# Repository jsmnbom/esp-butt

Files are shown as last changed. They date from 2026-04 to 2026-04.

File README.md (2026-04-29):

# esp-butt

Bluetooth intimate hardware (sex toys, etc) controller powered by [buttplug.io](https://buttplug.io/).

## Status

This project is still in fairly early development, it has some quirks and rough edges but is generally functional. Feel free to contact me if you are interested in building your own or contributing to the project.

## Documentation

<div align="center">
  <table>
    <tr>
      <td><h3 align="center"><a href="https://jsmnbom.github.io/esp-butt/">🏠<br/>Home</a></h3></td>
      <td><h3 align="center"><a href="https://jsmnbom.github.io/esp-butt/hardware">🛠️<br/>Hardware</a></h3></td>
      <td><h3 align="center"><a href="https://jsmnbom.github.io/esp-butt/hardware">📋<br/>BOM</a></h3></td>
      <td><h3 align="center"><a href="https://jsmnbom.github.io/esp-butt/hardware">📐<br/>Schematic</a></h3></td>
      <td><h3 align="center"><a href="https://jsmnbom.github.io/esp-butt/hardware">🟩<br/>PCB</a></h3></td>
      <td><h3 align="center"><a href="https://jsmnbom.github.io/esp-butt/hardware">🧊<br/>3D Models</a></h3></td>
      <td><h3 align="center"><a href="https://jsmnbom.github.io/esp-butt/firmware">⚙️<br/>Firmware</a></h3></td>
    </tr>
  </table>
</div>

## Contributing

I welcome contributions with open arms. If you have ideas, suggestions for improvements, or want to help out with development, please don't hesitate to reach out or submit a pull request.

## License

This project uses multiple licenses depending on the component:

| Component | License |
|---|---|
| `src/` — firmware source code | [MIT](https://opensource.org/licenses/MIT) |
| `docs/` — documentation | [MIT](https://opensource.org/licenses/MIT) |
| `cad/` — CAD files | [MIT](https://opensource.org/licenses/MIT) |
| `img/` — images | [CC BY-SA 4.0](https://creativecommons.org/licenses/by-sa/4.0/) |
| `pcb/` — PCB design | [CC BY-SA 4.0](https://creativecommons.org/licenses/by-sa/4.0/) |
| `pcb/kicad-config/10.0/colors/witchhazel.json` | [Apache-2.0](https://www.apache.org/licenses/LICENSE-2.0) — © [Thea Flowers](https://github.com/theacodes/witchhazel) |
| `pcb/esp-butt/3D/` — 3D models | Mixed — see [ATTRIBUTION.md](pcb/esp-butt/3D/ATTRIBUTION.md) |

## Thanks

Thanks to @qdot and the rest of the Buttplug.io contributors doing all the hard work of reverse engineering and protocol design, and also for being generally awesome.

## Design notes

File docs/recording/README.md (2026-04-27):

# Recording artifacts

This directory holds the raw session recording used to build the hero animation.

## How to populate

1. Run the firmware with recording enabled:
   ```bash
   ESP_BUTT_RECORD_SESSION=1 cargo run
   ```
2. Copy the recording files here:
   ```bash
   cp /tmp/esp-butt-session.ndjson docs/recording/session.ndjson
   cp /tmp/esp-butt-session.gif docs/recording/session.gif
   ```

   `session.ndjson` and `session.gif` are imported directly by Vite as part of the
   docs bundle — no separate build step is required.

## Files

- `session.ndjson` — raw event log (NDJSON, one event per line); frame events reference GIF frame indices
- `session.gif` — OLED frame snapshots stored as an animated GIF (used as a frame container)

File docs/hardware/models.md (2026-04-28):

# 3D Models

<script setup>
import {
  caseTopGlb, caseBottomGlb, encoderKnobGlb, sliderKnobGlb, powerSwitchCapGlb,
  caseTopStepUrl, caseBottomStepUrl, encoderKnobStepUrl,
  sliderKnobBodyStepUrl, sliderKnobInsertStepUrl, powerSwitchCapStepUrl,
} from '../.vitepress/theme/composables/models';
</script>

All parts are designed in [build123d](https://build123d.readthedocs.io/en/latest/) with custom helpers. Source notebooks are in the [`cad/`](https://github.com/jsmnbom/esp-butt/tree/main/cad) directory.

## Printing

The models are designed around my **Voron V2.4** printer. Other printers should work, but tolerances on snap-fits and clearance holes are tuned to my machine, so some adjustment may be needed.

**Material:** ABS is recommended for durability and dimensional stability. I use filament from [TM3D Filament](https://tm3dfilament.com/) (no affiliation).

**Slicer:** All parts were sliced with **OrcaSlicer**.

**General settings:** 0.15 mm layer height · 3 wall loops · 15–25% gyroid infill.

**Orientation:** All parts should be printed in the orientation in the step files.

## Case

2 wall loops is sufficient. Set outer wall width to **0.4 mm** — required for the slicer to handle the antenna cutout geometry correctly. Seam position and seam scarf/gap settings may need to be tuned to hide the seam on visible faces.

### Case Top

<StepDownload :files="{ name: 'case_top', url: caseTopStepUrl }" />

<ClientOnly>
  <CadViewer :url="caseTopGlb"/>
</ClientOnly>

### Case Bottom

<StepDownload :files="{ name: 'case_bottom', url: caseBottomStepUrl }" />

<ClientOnly>
  <CadViewer :url="caseBottomGlb"/>
</ClientOnly>

## Encoder knob

1 wall loop. Use a **concentric** top surface pattern to give the concave top a smooth feel.

<StepDownload :files="{ name: 'encoder_knob', url: encoderKnobStepUrl }" />

<ClientOnly>
  <CadViewer :url="encoderKnobGlb"/>
</ClientOnly>

## Slider knob

**Body:** 1 wall loop. Use an **aligned rectilinear** top surface pattern with infill direction set to **0°** — this makes the knob divots noticeably smoother.

**Inserts:** Print flat. Use **0.12 mm layer height** and a very slow print speed — these are small precision parts and quality matters here.

<StepDownload :files="[{ name: 'slider_knob_body', url: sliderKnobBodyStepUrl }, { name: 'slider_knob_insert', url: sliderKnobInsertStepUrl }]" />

<ClientOnly>
  <CadViewer :url="sliderKnobGlb"/>
</ClientOnly>

## Power switch cap

General settings apply.

<StepDownload :files="{ name: 'power_switch_cap', url: powerSwitchCapStepUrl }" />

<ClientOnly>
  <CadViewer :url="powerSwitchCapGlb"/>
</ClientOnly>

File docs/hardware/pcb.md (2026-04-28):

# PCB

PCB design files are available in the [`pcb/`](https://github.com/jsmnbom/esp-butt/tree/main/pcb) directory. The PCB was designed using KiCad, and the source files are included.

<PCBViewer />

## Manufacturing

The PCBs for this project were manufactured at [Aisler](https://aisler.net). They are a European fab, I went with them for their strong focus on hobbyist and maker customers, good reviews for quality and support, and convenient shipping options.

Aisler also offers two stackable discounts worth knowing about:

- **LOGO Hack** — a checkbox during checkout that grants a 25% discount in exchange for the Aisler logo being placed on the board (the PCB already has a designated area for this).
- **Part Professional program** — when boards include parts from specific vendors you get a discount on the PCB cost. For this PCB the rotary encoder and 1x4 pin socket header can be sourced from Würth Elektronik which take advantage of this program.

With these combined, 3 PCBs including fast shipping and the KiCad sponsor contribution comes to around **€35** at the time of writing.

Alternative fabs such as JLCPCB or PCBWay may offer lower prices, but I have not tested them with this specific board. They may require adjustments to export settings and may have longer turnaround times depending on shipping options. However the board overall is quite simple and should be compatible with a wide range of manufacturers.

## 3D Preview

<script setup>
import { pcbGlb } from '../.vitepress/theme/composables/models';
</script>

<ClientOnly>
  <CadViewer :url="pcbGlb"/>
</ClientOnly>

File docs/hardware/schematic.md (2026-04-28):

---
aside: false
---

# Schematic

<SchematicViewer />

## Design Notes

### Power switch

S2 is a **DPDT (double pole, double throw)** slide switch used to cut power in two places simultaneously. One pole interrupts the VCC rail to all peripherals — the display, encoder, and sliders — so they draw no current when off. The other pole holds the ESP32-S3's **EN pin low**, which suspends the chip entirely rather than leaving it in an idle loop.

This is a pragmatic design choice that avoids idle current draw without requiring deep sleep firmware support. The trade-off is that it's a somewhat unconventional use of the EN pin. A cleaner future revision would use proper deep sleep mode combined with a P-channel MOSFET or a dedicated load switch IC on the battery rail, which would allow the firmware to participate in the power-down sequence and wake from user input.

### Battery

The controller is powered by a **3.7 V LiPo cell** (600 mAh recommended, see links in BOM) connected via a JST-PH connector (J2). There is no on-board charging circuit — the battery must be charged externally, for example with a standalone TP4056 module. This keeps the board simple and small, but means you'll need to disconnect the battery and charge it separately.

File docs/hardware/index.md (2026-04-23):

# Hardware Overview

esp-butt is a handheld Bluetooth controller built around the ESP32-S3. It connects to BLE intimate devices running the [Buttplug protocol](https://buttplug.io/) and lets you control them through a small physical interface: an OLED display, a rotary encoder, and three analog sliders.

## Components

| Component | Details |
|---|---|
| **MCU** | ESP32-S3 (Xtensa dual-core, 240 MHz, Wi-Fi + BLE) |
| **Display** | 128×64 OLED, I²C (SH1106) |
| **Encoder** | Rotary encoder with push button — menu navigation and selection |
| **Sliders** × 2 | 10 kΩ linear potentiometers — analog control of device features (intensity, oscillation, etc.) |
| **Power** | LiPo battery |

## Sections

- **[Bill of Materials](/hardware/bom)** — Full parts list with quantities and purchase links.
- **[Schematic](/hardware/schematic)** — Circuit diagram for the controller board.
- **[PCB](/hardware/pcb)** — KiCad PCB layout and 3D preview.
- **[3D Models](/hardware/models)** — Printable case, knobs, and power switch cap.

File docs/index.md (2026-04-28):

---
layout: home

hero:
  name: "esp-butt"
  text: "A physical controller for intimate devices"
  tagline: "No phone. No app. Just knobs, sliders, and hundreds of compatible toys."
  actions:
    - theme: brand
      text: Hardware
      link: /hardware/
    - theme: alt
      text: Firmware
      link: /firmware/
    - theme: alt
      text: GitHub
      link: https://github.com/jsmnbom/esp-butt

features:
  - icon: i-noto-v1:no-mobile-phones
    title: No phone required
    details: A standalone physical controller — power it on, pick a device from the OLED menu, and you're in control. No app, no pairing ceremony.
  - icon: i-logos:bluetooth
    title: Works with hundreds of toys
    details: Built on Buttplug.io, the open intimacy device protocol. If your toy speaks BLE and Buttplug knows it, this controller can drive it.
  - icon: i-whh:controlpanel
    title: Hands-on controls
    details: Two analog sliders and a rotary encoder with push-click give precise, tactile control over intensity — no touchscreen fumbling.
  - icon: i-logos:opensource
    title: Fully open source
    details: KiCad schematics, 3D-printable case, and Rust firmware — everything needed to build, modify, or extend your own unit.
    link: /hardware/
    linkText: Build one
---

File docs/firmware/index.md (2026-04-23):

# Firmware

## Flashing Pre-built Firmware

Pre-built firmware binaries are published with each [GitHub release](https://github.com/jsmnbom/esp-butt/releases). Download the latest `.bin` file from there.

### Flashing with espflash

Install [espflash](https://github.com/esp-rs/espflash):

```sh
cargo install espflash --locked
```

Then flash the downloaded binary:

```sh
espflash flash --chip esp32s3 esp-butt.bin
```

## Building from Source

### Prerequisites

Install the Espressif toolchain:

```sh
cargo install espup --locked
espup -t esp32s3 -s --toolchain-version 1.93.0.0
```

The toolchain uses the `esp` channel (Espressif's Xtensa fork). Target triple: `xtensa-esp32s3-espidf`.

### Build and Flash

Switch the build target to `xtensa-esp32s3-espidf` in `.cargo/config.toml` (and `.vscode/settings.json` for rust-analyzer):

```sh
cargo build          # debug build
cargo run            # build, flash, and open serial monitor
```

`cargo run` flashes via `espflash flash --monitor` as configured in `.cargo/config.toml`.

### Desktop Mock (no device needed)

Switch the target to `x86_64-unknown-linux-gnu`:

```sh
cargo run
```

Requires the [kitty](https://sw.kovidgoyal.net/kitty/) terminal emulator. The display output renders in a separate kitty window. Use mouse to interact with sliders and keyboard arrows + Enter to simulate button presses.

---

## Architecture

- `src/app/` — platform-independent state machine and UI screens
- `src/ble/` — NimBLE BLE scanning and GATT client (ESP only)
- `src/buttplug/` — Buttplug server/client, device config, deferred connection approval
- `src/hw/` — display (I2C OLED), encoder, sliders, ticker; split into `hw/esp/` and `hw/mock/`
- `src/utils/` — FreeRTOS task spawning, PSRAM heap, logging

CPU affinity: BLE on Core 0, app logic on Core 1.

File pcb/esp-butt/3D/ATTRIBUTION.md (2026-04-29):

# 3D Model Attribution

| File(s) | Source | License / Terms |
|---|---|---|
| `AZ-Delivery - OLED13 IIC -0.6.step`<br>`AZ-Delivery - OLED13 IIC - split.step` | Modified from [GrabCAD](https://grabcad.com/library/1-3-oled-display-128x64-1) | [GrabCAD Terms of Use](https://grabcad.com/terms) |
| `C_Disc_D5.0mm_W2.5mm_P2.50mm.step`<br>`JST_PH_B2B-PH-K_1x02_P2.00mm_Vertical.step`<br>`PinSocket_1x04_P2.54mm_Vertical.step`<br>`R_Axial_DIN0207_L6.3mm_D2.5mm_P10.16mm_Horizontal.step` | [KiCad official library](https://gitlab.com/kicad/libraries/kicad-packages3D) | [CC BY-SA 4.0](https://creativecommons.org/licenses/by-sa/4.0/) |
| `PBH2UEESNPNAGX.step` | [SnapEDA](https://www.snapeda.com/parts/PBH2UEESNPNAGX/E-Switch/view-part/) | [SnapEDA Terms of Use](https://www.snapeda.com/about/terms/) |
| `PEC12R-4225F-S0024.step` | [SnapEDA](https://www.snapeda.com/parts/PEC12R-4225F-S0024/Bourns/view-part/) | [SnapEDA Terms of Use](https://www.snapeda.com/about/terms/) |
| `PTA4543-2015DPB103-fixed.step`<br>`PTA4543-2015DPB103-fixed2.step` | Modified from [ComponentSearchEngine](https://componentsearchengine.com/part-view/PTA4543-2015DPB103/Bourns) | [Samacsys Terms of Use](https://componentsearchengine.com/terms-and-conditions) |
| `XIAO-ESP32S3 v2Seeed Studio XIAO-ESP32-S3.step` | [Seeed Studio](https://files.seeedstudio.com/wiki/SeeedStudio-XIAO-ESP32S3/res/seeed-studio-xiao-esp32s3-3d_model.zip) | [Seeed Studio Terms](https://www.seeedstudio.com/terms-of-use.html) |

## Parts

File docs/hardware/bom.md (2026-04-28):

---
aside: false
---

# Bill of Materials

> **Note:** The purchase links listed here may include referral or promotional codes. The specific parts linked have not all been individually tested, but are strongly believed to be functionally compatible with the design. If you source equivalent parts elsewhere, check the datasheet to confirm pinout and electrical ratings match.

<ClientOnly>
  <BomTable />
</ClientOnly>

> **Note:** Add `Source_EU` and `Source_US` URL fields to components in KiCad to populate the buy links above.

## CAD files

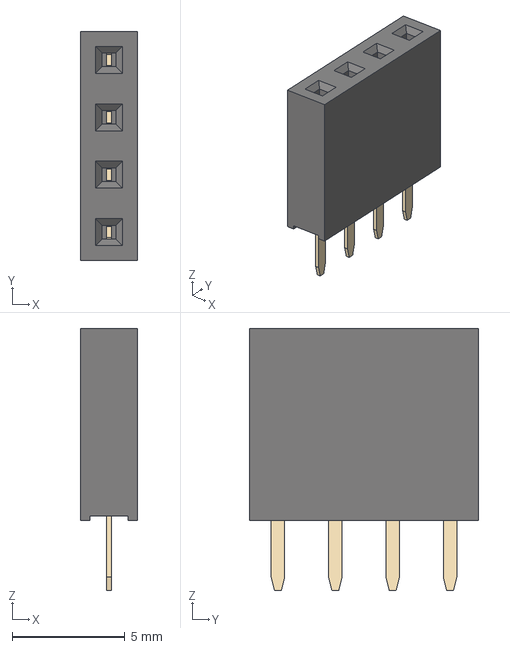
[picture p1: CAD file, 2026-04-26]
pcb/esp-butt/3D/PinSocket_1x04_P2.54mm_Vertical.step
2.54 x 10.2 x 11.6 mm

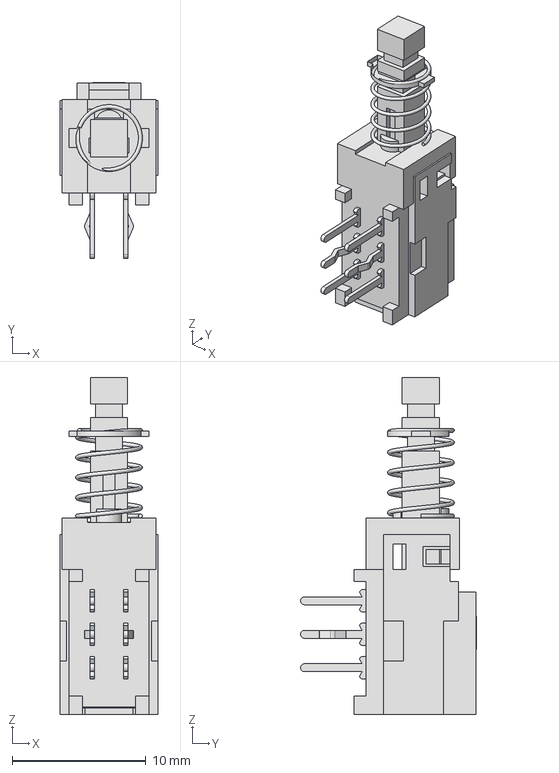
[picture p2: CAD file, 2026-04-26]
pcb/esp-butt/3D/PBH2UEESNPNAGX.step
7.30 x 13.2 x 25.2 mm

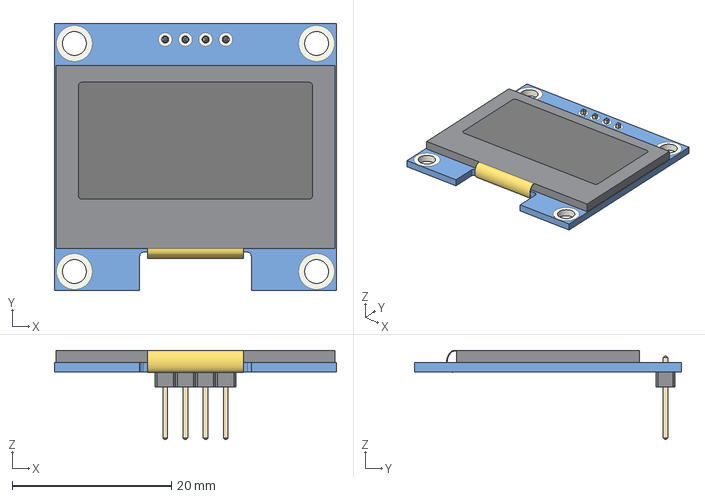
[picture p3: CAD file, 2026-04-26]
pcb/esp-butt/3D/AZ-Delivery - OLED13 IIC - split.step
35.4 x 33.5 x 11.2 mm
Base
Screen

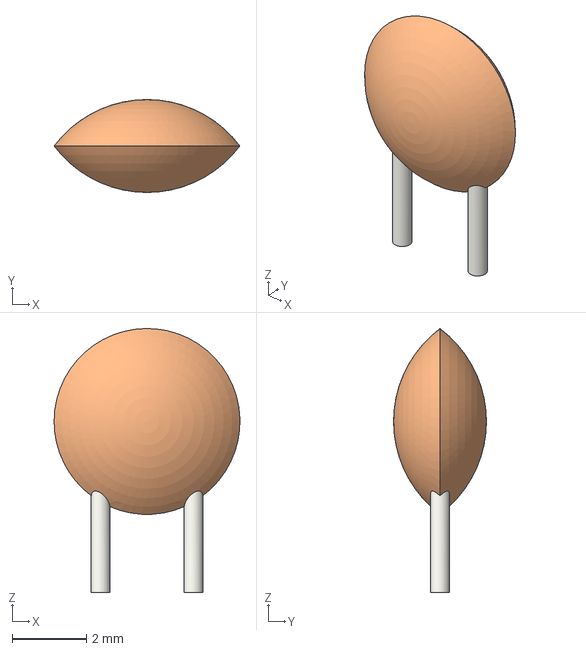
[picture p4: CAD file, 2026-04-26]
pcb/esp-butt/3D/C_Disc_D5.0mm_W2.5mm_P2.50mm.step
5.00 x 2.50 x 7.10 mm

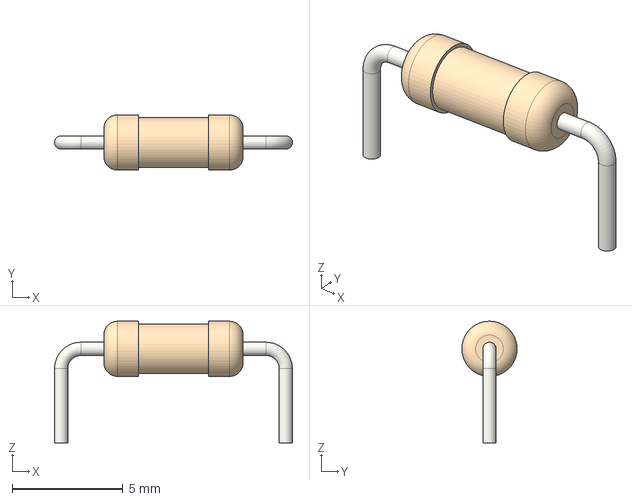
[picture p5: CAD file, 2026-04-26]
pcb/esp-butt/3D/R_Axial_DIN0207_L6.3mm_D2.5mm_P10.16mm_Horizontal.step
10.8 x 2.50 x 5.50 mm

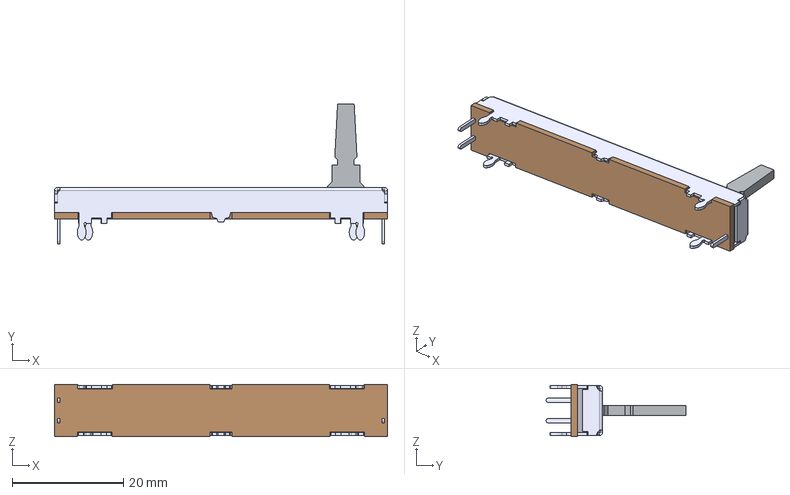
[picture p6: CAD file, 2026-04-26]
pcb/esp-butt/3D/PTA4543-2015DPB103-fixed2.step
60.0 x 25.2 x 9.40 mm
Shield
PCB
Pin1
Pin2
Pin3
Inner
Lever

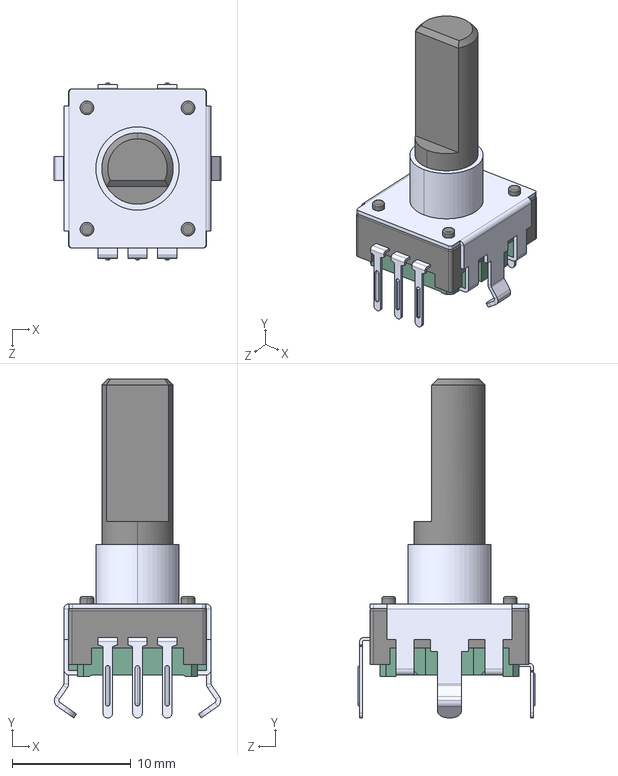
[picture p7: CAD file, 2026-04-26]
pcb/esp-butt/3D/PEC12R-4225F-S0024.step
14.0 x 28.5 x 14.9 mm

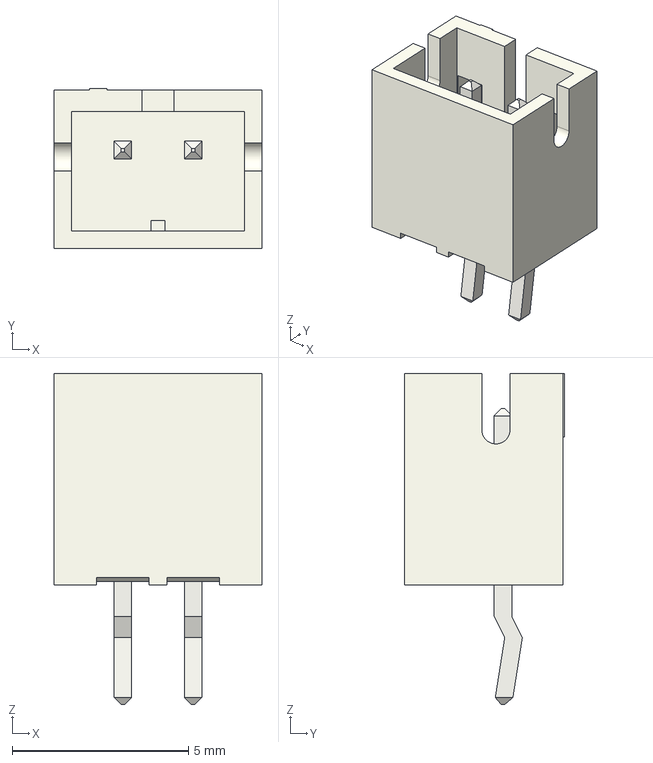
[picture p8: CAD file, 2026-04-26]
pcb/esp-butt/3D/JST_PH_B2B-PH-K_1x02_P2.00mm_Vertical.step
5.90 x 4.55 x 9.40 mm

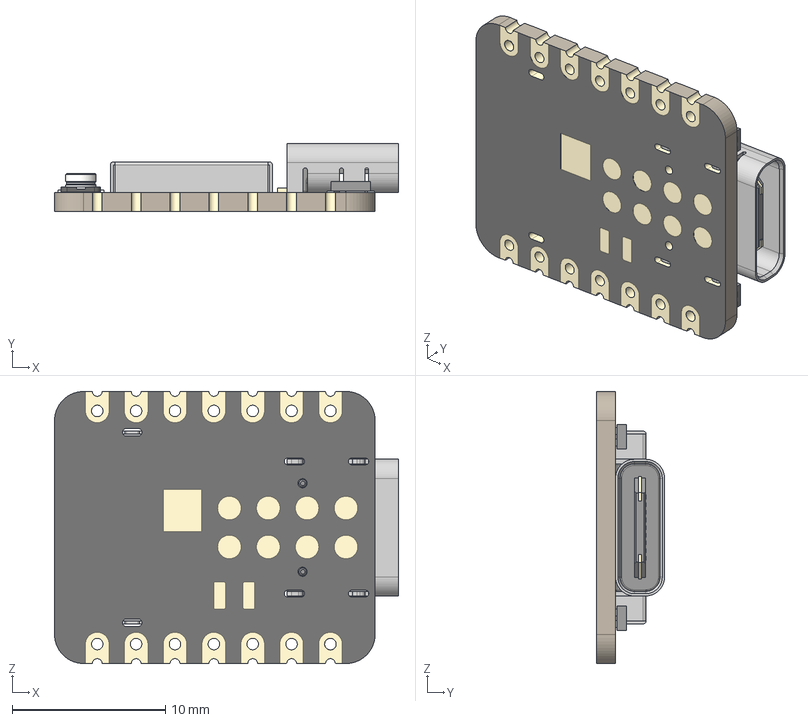
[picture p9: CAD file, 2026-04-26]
pcb/esp-butt/3D/XIAO-ESP32S3 v2Seeed Studio XIAO-ESP32-S3.step
22.5 x 4.46 x 17.8 mm
BOSS-EXTRUDE14_8_
BOSS-EXTRUDE7_4_
BOSS-EXTRUDE7_3_
BOSS-EXTRUDE14_4_
BOSS-EXTRUDE14_2_
BOSS-EXTRUDE14_11_
BOSS-EXTRUDE7_7_
BOSS-EXTRUDE14_9_
BOSS-EXTRUDE14_3_
BOSS-EXTRUDE14_7_
MIRROR2
BOSS-EXTRUDE14_5_
BOSS-EXTRUDE14_12_
BOSS-EXTRUDE7_8_
BOSS-EXTRUDE7_1_
BOSS-EXTRUDE14_10_
BOSS-EXTRUDE7_9_
BOSS-EXTRUDE14_6_
BOSS-EXTRUDE14_1_
BOSS-EXTRUDE7_6_
BOSS-EXTRUDE7_2_
CUT-EXTRUDE5
BOSS-EXTRUDE7_5_
Shield
Pins x 2
Pins001 x 2
Pins002 x 2
Pins003 x 2
U.FL-R-SMT-1_10_ v1

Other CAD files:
pcb/esp-butt/3D/AZ-Delivery - OLED13 IIC -0.6.step
pcb/esp-butt/3D/PTA4543-2015DPB103-fixed.step

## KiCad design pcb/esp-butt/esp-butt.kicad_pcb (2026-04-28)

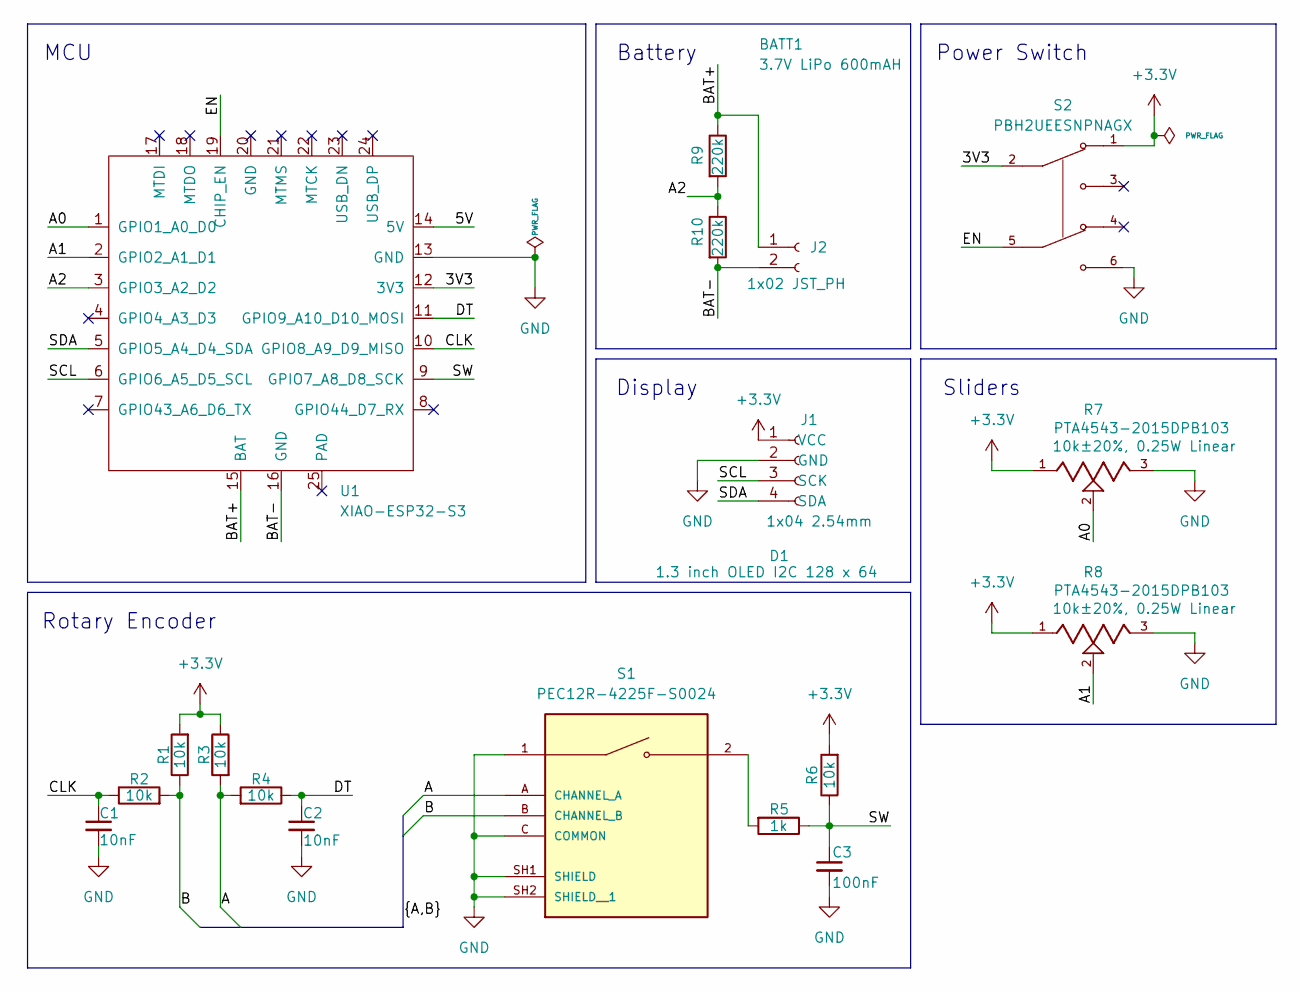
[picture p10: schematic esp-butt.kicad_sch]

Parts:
BATT1: 3.7V LiPo 600mAH
C1, C2: 10nF; C_Disc_D5.0mm_W2.5mm_P2.50mm
C3: 100nF; C_Disc_D5.0mm_W2.5mm_P2.50mm
D1: 1.3 inch OLED I2C 128 x 64
J1: 1x04 2.54mm; OLED_128x64_1.3in_I2C_Socket_Vertical
J2: 1x02 JST_PH; JST_PH_B2B-PH-K_1x02_P2.00mm_Vertical
R1, R2, R3, R4, R6: 10k; R_Axial_DIN0207_L6.3mm_D2.5mm_P10.16mm_Horizontal
R5: 1k; R_Axial_DIN0207_L6.3mm_D2.5mm_P10.16mm_Horizontal
R7, R8: PTA4543-2015DPB103; TRIM_PTA4543-2015DPB103; PARTREV 04/21
R9, R10: 220k; R_Axial_DIN0207_L6.3mm_D2.5mm_P10.16mm_Horizontal
S1: PEC12R-4225F-S0024; XDCR_PEC12R-4225F-S0024; PARTREV 07/21
S2: PBH2UEESNPNAGX; SW_PBH2UEESNPNAGX; PARTREV E
U1: XIAO-ESP32-S3; XIAO-ESP32-S3-DIP+

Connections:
+3.3V: J1.1 (VCC), R1.2, R3.1, R6.2, R7.1, R8.1, S2.1
/3V3: S2.2, U1.12 (3V3)
/5V: U1.14 (5V)
/A: R3.2, R4.2, S1.A (CHANNEL_A)
/A0: R7.2, U1.1 (GPIO1_A0_D0)
/A1: R8.2, U1.2 (GPIO2_A1_D1)
/A2: R9.2, R10.1, U1.3 (GPIO3_A2_D2)
/B: R1.1, R2.2, S1.B (CHANNEL_B)
/BAT+: J2.1, R9.1, U1.15 (BAT)
/BAT-: J2.2, R10.2, U1.16 (GND)
/CLK: C1.1, R2.1, U1.10 (GPIO8_A9_D9_MISO)
/DT: C2.1, R4.1, U1.11 (GPIO9_A10_D10_MOSI)
/EN: S2.5, U1.19 (CHIP_EN)
/SCL: J1.3 (SCK), U1.6 (GPIO6_A5_D5_SCL)
/SDA: J1.4 (SDA), U1.5 (GPIO5_A4_D4_SDA)
/SW: C3.1, R5.1, R6.1, U1.9 (GPIO7_A8_D8_SCK)
GND: C1.2, C2.2, C3.2, J1.2 (GND), R7.3, R8.3, S1.1, S1.C (COMMON), S1.SH1 (SHIELD), S1.SH2 (SHIELD__1), S2.6, U1.13 (GND)
unnamed: R5.2, S1.2

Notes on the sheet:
Display
Power Switch
Rotary Encoder
Sliders
MCU
Battery

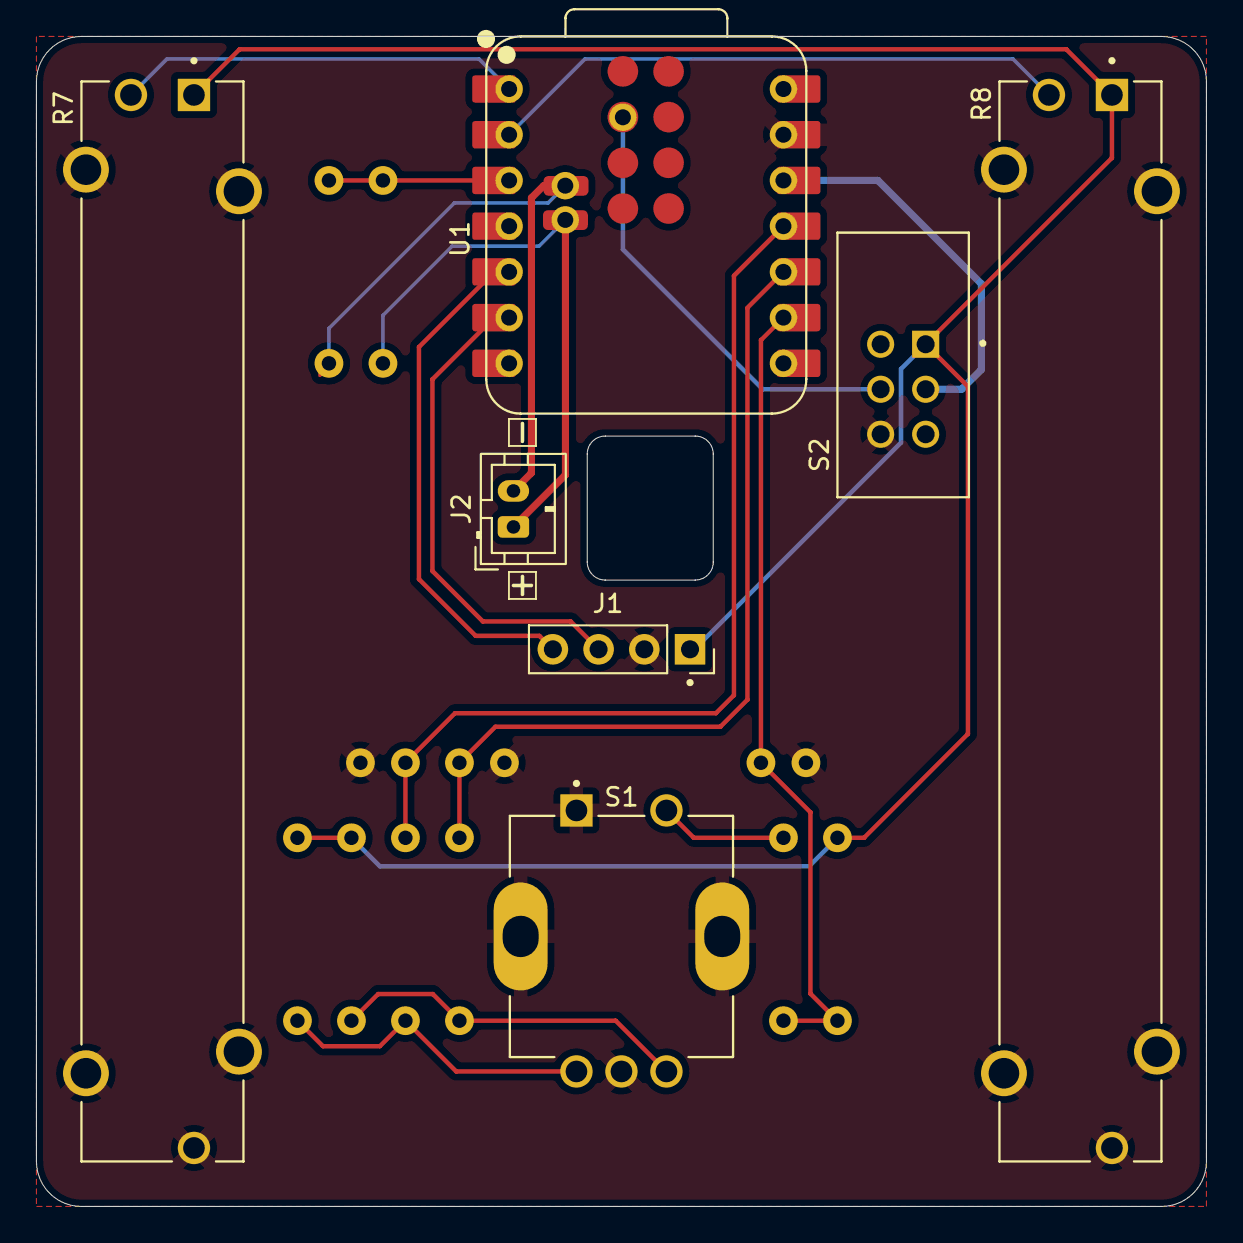
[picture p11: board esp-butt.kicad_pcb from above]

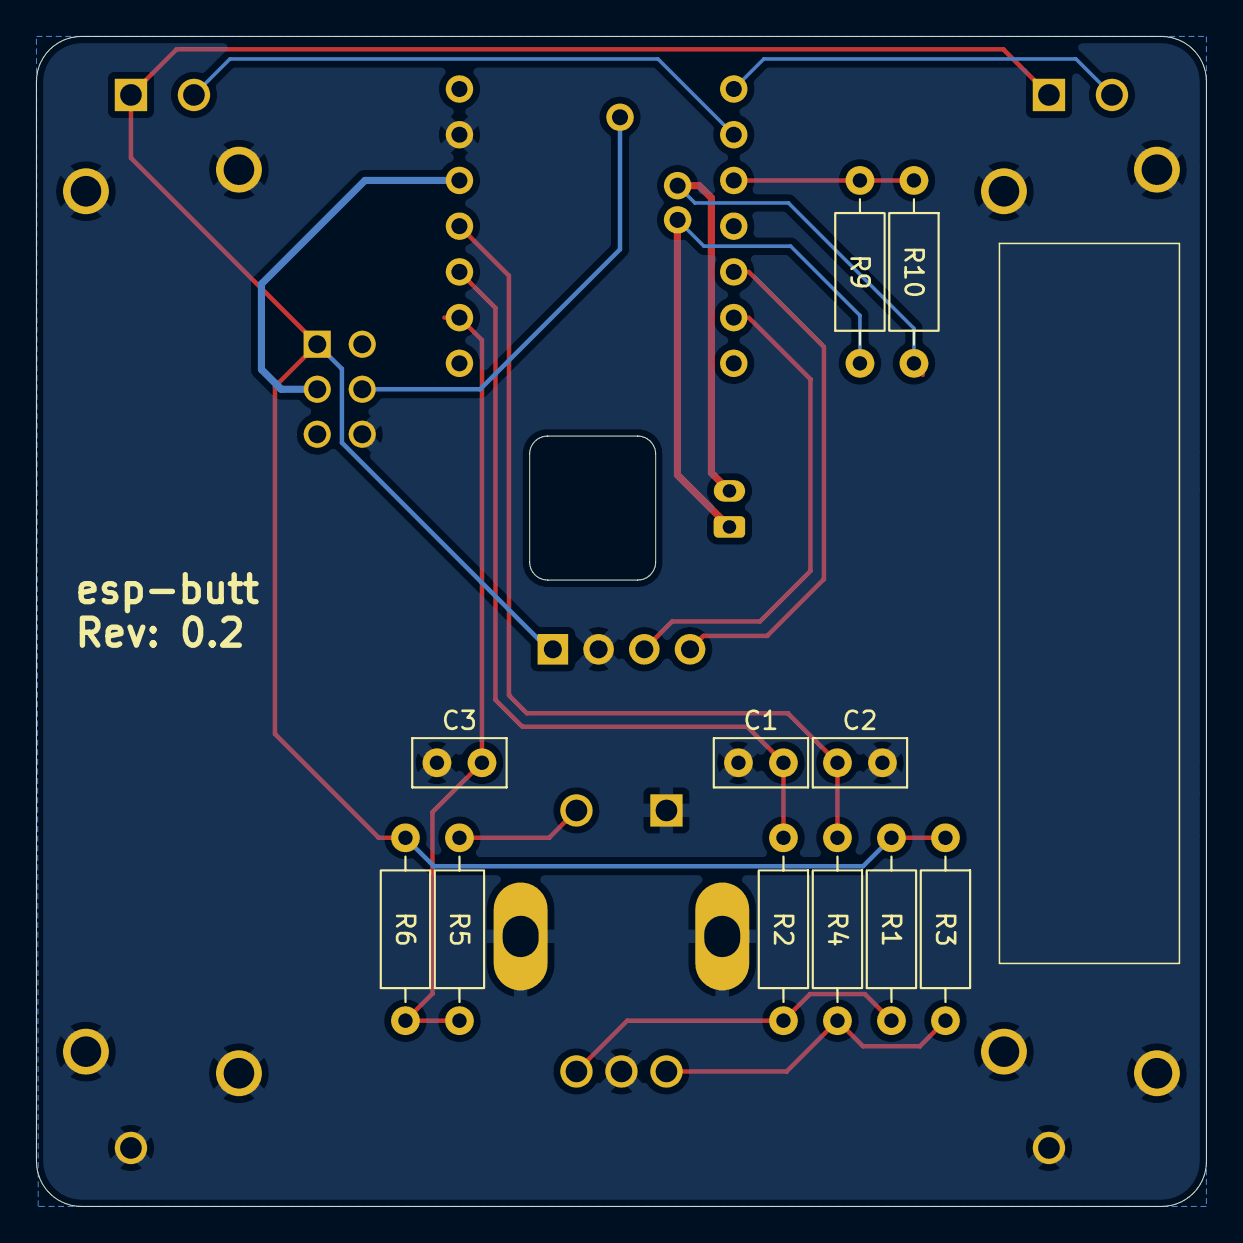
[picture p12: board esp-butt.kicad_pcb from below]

Board: 2 copper layers, 65.0 x 65.0 mm, 18 parts (11 on the bottom side), 17 nets.

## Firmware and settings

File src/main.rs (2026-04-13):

mod app;
mod buttplug;
mod hw;
mod img;
mod utils;

#[cfg(target_os = "espidf")]
mod ble;

#[cfg(target_os = "espidf")]
fn main() -> anyhow::Result<()> {
  use futures_concurrency::prelude::*;

  esp_idf_svc::sys::link_patches();

  tracing_log::LogTracer::init().unwrap();

  utils::log::Subscriber::new(tracing::Level::DEBUG)
    .with_filter("esp_idf_svc::timer", tracing::Level::WARN)
    .with_filter("buttplug", tracing::Level::DEBUG)
    .install();

  hw::init()?;
  ble::init();
  buttplug::init();

  // utils::report::start_reporting(core::time::Duration::from_secs(5));

  log::info!("Hello, world!");

  let peripherals = esp_idf_svc::hal::peripherals::Peripherals::take().unwrap();

  let display = hw::Display::new(
    peripherals.i2c0,
    peripherals.pins.gpio5,
    peripherals.pins.gpio6,
  )?;

  let adc = hw::AdcInputs::new(
    peripherals.adc1,
    (peripherals.pins.gpio1, peripherals.pins.gpio2),
    peripherals.pins.gpio3,
  )?;

  let encoder = hw::Encoder::new(
    peripherals.pins.gpio9,
    peripherals.pins.gpio8,
    peripherals.pins.gpio7,
  )?;

  let ticker = hw::Ticker::new()?;

  let input_event_stream = Box::pin((adc.stream(), encoder.stream(), ticker.stream()).merge());

  let app = app::App::new(display, adc);

  esp_idf_svc::hal::task::block_on(async move { app.main(input_event_stream).await })
}

#[cfg(not(target_os = "espidf"))]
#[global_allocator]
static GLOBAL: tracing_tracy::client::ProfiledAllocator<std::alloc::System> =
  tracing_tracy::client::ProfiledAllocator::new(std::alloc::System, 100);

#[cfg(not(target_os = "espidf"))]
#[tokio::main(flavor = "current_thread")]
async fn main() -> anyhow::Result<()> {
  use tracing_subscriber::layer::SubscriberExt;

  tracing_log::LogTracer::init()?;

  tracy_client::register_demangler!();

  tracing::subscriber::set_global_default(
    tracing_subscriber::fmt()
      .with_max_level(tracing::Level::DEBUG)
      .with_writer(std::io::stderr)
      .finish()
      .with(tracing_tracy::TracyLayer::default()),
  )?;

  buttplug::init();

  log::info!("Hello, world!");

  let hw::HardwareMock {
    display,
    input_stream,
  } = hw::HardwareMock::new()?;

  let app = app::App::new(display);

  app.main(input_stream).await
}

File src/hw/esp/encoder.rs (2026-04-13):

use esp_idf_svc::hal::delay::BLOCK;
use esp_idf_svc::hal::gpio::{InputPin, InterruptType};
use esp_idf_svc::hal::task::queue::Queue;
use esp_idf_svc::sys;
use esp_idf_svc::sys::{EspError, esp};
use futures::Stream;
use tokio::sync::broadcast;

use crate::{
  app::{AppEvent, NavigationEvent},
  esp_timer_create,
  gpio_isr_handler_add,
  hw::gpio_input_config,
  utils::{self, task::spawn, task::Core},
};

pub struct Encoder {
  tx: broadcast::Sender<AppEvent>,
}

const BUTTON_TICK_MS: u64 = 15;
const BUTTON_DEBOUNCE_TICKS: u8 = 3;

enum ButtonState {
  PressDownCheck,
  PressUpCheck,
}

/// ISR argument for the rotary encoder pins.
/// Uses raw pointers to the ISR-safe queue and notification instead of the
/// broadcast::Sender, which internally uses a pthread_mutex and must never be
/// called from an ISR context.
struct EncoderArg {
  pin_a: u8,
  pin_b: u8,
  queue: *const Queue<NavigationEvent>,
}

// Safety: PinIsrArg is only ever accessed from a single ISR handler.
unsafe impl Send for EncoderArg {}

struct BtnArg {
  pin: i32,
  queue: *const Queue<NavigationEvent>,
  level: bool,
  debounce: u8,
  state: ButtonState,
  timer_handle: sys::esp_timer_handle_t,
  timer_active: bool,
}

// Safety: Button is only ever accessed from the button ISR / timer callback.
unsafe impl Send for BtnArg {}

impl Encoder {
  pub fn new(
    pin_a: impl InputPin + 'static,
    pin_b: impl InputPin + 'static,
    pin_btn: impl InputPin + 'static,
  ) -> Result<Self, EspError> {
    let (tx, _) = broadcast::channel(16);

    gpio_input_config(&pin_a, Some(InterruptType::AnyEdge))?;
    gpio_input_config(&pin_b, None)?;
    gpio_input_config(&pin_btn, Some(InterruptType::NegEdge))?;

    // Leak the queue so it gets a 'static lifetime that is safe to share
    // with ISR handlers via raw pointer.
    let queue: &'static Queue<NavigationEvent> = Box::leak(Box::new(Queue::new(16)));

    let encoder_arg = Box::into_raw(Box::new(EncoderArg {
      pin_a: pin_a.pin() as u8,
      pin_b: pin_b.pin() as u8,
      queue,
    }));
    gpio_isr_handler_add!(pin_a, Encoder::encoder_isr_handler, encoder_arg)?;

    let btn_arg = Box::into_raw(Box::new(BtnArg {
      pin: pin_btn.pin() as i32,
      queue,
      level: true,
      debounce: 0,
      state: ButtonState::PressDownCheck,
      timer_handle: core::ptr::null_mut(),
      timer_active: false,
    }));

    let btn_timer_handle = esp_timer_create!(Encoder::btn_isr_handler, encoder_button, btn_arg)?;
    let btn = unsafe { &mut *(btn_arg as *mut BtnArg) };
    btn.timer_handle = btn_timer_handle;

    gpio_isr_handler_add!(pin_btn, Encoder::btn_isr_handler, btn_arg)?;

    Self::spawn_task(tx.clone(), queue);

    Ok(Encoder { tx })
  }

  fn spawn_task(tx: broadcast::Sender<AppEvent>, queue: &'static Queue<NavigationEvent>) {
    // Bridge task: blocks on the ISR-safe queue and forwards events to the
    // broadcast channel.  The broadcast::Sender uses a mutex, which is only
    // safe to call from a normal task — never from an ISR.
    // send_back() from the ISR uses xQueueGenericSendFromISR, which wakes the
    // FreeRTOS task blocked here on xQueueReceive(BLOCK) directly.
    spawn(
      async move {
        loop {
          if let Some((event, _)) = queue.recv_front(BLOCK) {
            let _ = tx.send(AppEvent::Navigation(event));
          }
        }
      },
      c"encoder",
      4 * 1024,
      Core::App,
      8,
    );
  }

  pub fn subscribe(&self) -> broadcast::Receiver<AppEvent> {
    self.tx.subscribe()
  }

  pub fn stream(&self) -> impl Stream<Item = AppEvent> + use<> {
    utils::stream::convert_broadcast_receiver_to_stream(self.subscribe())
  }

  fn btn_isr_handler(btn: &mut BtnArg) {
    let read_level = unsafe { sys::gpio_get_level(btn.pin) != 0 };
    if read_level != btn.level {
      btn.debounce += 1;
      if btn.debounce >= BUTTON_DEBOUNCE_TICKS {
        btn.level = read_level;
        btn.debounce = 0;
      }
    } else {
      btn.debounce = 0;
    }

    match btn.state {
      ButtonState::PressDownCheck => {
        if !btn.level {
          // ISR-safe: send_back uses xQueueGenericSendFromISR when
          // interrupt::active() is true, which wakes the bridge task.
          let queue = unsafe { &*btn.queue };
          let _ = queue.send_back(NavigationEvent::Select, 0);
          btn.state = ButtonState::PressUpCheck;
        }
        if !btn.timer_active {
          unsafe { sys::esp_timer_start_periodic(btn.timer_handle, BUTTON_TICK_MS * 1_000) };
          btn.timer_active = true;
        }
      }
      ButtonState::PressUpCheck => {
        if btn.level {
          btn.state = ButtonState::PressDownCheck;
          if btn.timer_active {
            unsafe { sys::esp_timer_stop(btn.timer_handle) };
            btn.timer_active = false;
          }
        }
      }
    }
  }

  fn encoder_isr_handler(arg: &mut EncoderArg) {
    let a = unsafe { sys::gpio_get_level(arg.pin_a.into()) != 0 };
    let b = unsafe { sys::gpio_get_level(arg.pin_b.into()) != 0 };

    // Clockwise: { a: false, b: false } followed by { a: true, b: true } -> Up
    // Counterclockwise: { a: false, b: true } followed by { a: true, b: false } -> Down

    let event = if a && b {
      NavigationEvent::Up
    } else if a && !b {
      NavigationEvent::Down
    } else {
      return;
    };

    // ISR-safe: send_back uses xQueueGenericSendFromISR when
    // interrupt::active() is true, which wakes the bridge task.
    let queue = unsafe { &*arg.queue };
    let _ = queue.send_back(event, 0);
  }
}

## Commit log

2026-02-18 working
    well - at least it's connecting to a device
2026-03-07 Add PCB
    ... i wonder what the license of those footprint files is...?
    [esp-butt.kicad_pcb, esp-butt.kicad_sch]
2026-03-13 More stuffs
    [esp-butt.kicad_pcb, esp-butt.kicad_sch]
2026-03-15 oh wow stuff!
    [size.csv, size2.csv]
2026-03-21 More worky
    [size.csv, size2.csv]
2026-04-02 cad updates
2026-04-23 More work + docs
    [AZ-Delivery - OLED13 IIC - moved 0.75.step, AZ-Delivery - OLED13 IIC.stp, esp-butt.kicad_pcb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]
2026-04-23 Pin espup to v0.17.1 and cache ldproxy binary
    Agent-Logs-Url: https://github.com/jsmnbom/esp-butt/sessions/dd848015-c231-475d-9a6b-b27d4dc768ed
2026-04-26 Add Pillow dependency and implement session recording feature
    - Added "pillow" to dependencies in pyproject.toml and uv.lock.
    - Enhanced HardwareMock to support session recording, including:
    - New spawn_recorder_task function to handle event and frame recording.
    - Logic to create a temporary directory for storing frames.
    - Recording navigation and slider events to a specified NDJSON file.
    - Saving frames as PNG images during the session.
    [AZ-Delivery - OLED13 IIC - moved 0.75.step, AZ-Delivery - OLED13 IIC - split.step, AZ-Delivery - OLED13 IIC -0.6.step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]
2026-04-27 feat: enhance recording functionality and improve documentation
    - Added `useRecording` composable to load and process session recordings with GIF frames.
    - Updated CSS for better layout and responsiveness of the hero image area.
    - Integrated new components in the theme index and improved model imports in documentation.
    - Refactored model download components to use dynamic URLs.
    - Updated TypeScript configuration to include path mappings for easier imports.
    - Enhanced NDJSON module declaration for better type safety.
    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
2026-04-28 Documentation updates
    [esp-butt.kicad_pcb, esp-butt.kicad_sch]

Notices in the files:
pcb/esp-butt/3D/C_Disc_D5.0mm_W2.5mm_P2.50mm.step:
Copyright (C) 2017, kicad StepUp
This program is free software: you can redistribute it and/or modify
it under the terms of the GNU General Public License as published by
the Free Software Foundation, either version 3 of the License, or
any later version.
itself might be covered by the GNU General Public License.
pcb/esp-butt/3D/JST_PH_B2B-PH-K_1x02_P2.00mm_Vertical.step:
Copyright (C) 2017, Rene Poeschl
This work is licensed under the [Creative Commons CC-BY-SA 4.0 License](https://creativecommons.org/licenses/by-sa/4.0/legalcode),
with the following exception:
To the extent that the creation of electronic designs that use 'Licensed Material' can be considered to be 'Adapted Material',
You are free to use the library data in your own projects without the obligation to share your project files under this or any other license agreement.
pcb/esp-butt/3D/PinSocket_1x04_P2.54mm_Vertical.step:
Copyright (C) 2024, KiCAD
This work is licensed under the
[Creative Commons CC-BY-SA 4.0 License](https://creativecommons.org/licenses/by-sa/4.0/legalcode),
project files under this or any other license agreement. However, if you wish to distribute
